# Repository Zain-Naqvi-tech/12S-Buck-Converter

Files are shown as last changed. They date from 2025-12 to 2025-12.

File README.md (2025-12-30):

## Overview
This project is a custom DC-DC Step-Down (Buck) Converter designed in Altium Designer. It takes a higher input voltage and efficiently steps it down to a lower, stable output voltage suitable for powering microcontrollers, sensors, or other low-voltage electronics.

## Specifications
| Parameter | Value |
| :--- | :--- |
| **Input Voltage (Vin)** | 36V - 50.4V |
| **Output Voltage (Vout)** | 5V |
| **Max Output Current** | 3A |
| **Switching Frequency** | 500kHz |
| **Main Controller IC** | LMR16030SDDAR |

Buck Converter PCB 3D Image

Buck Converter PCB 2D Image

Buck Converter Schematic Image

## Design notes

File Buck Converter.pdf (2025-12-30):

### Buck Converter 12S - 5V at 3A

We are required to create a buck converter that steps down voltage from the 12S range (36V to 50.4V) to 5V at 3A.

This is a high voltage input. Therefore, I will be using LMR16030SDDAR as the IC. This IC functions as a high-speed on/off switch which is needed for a buck converter. This is mainly used for the calculation of the Duty Cycle, which is a percentage of time the switch is on.

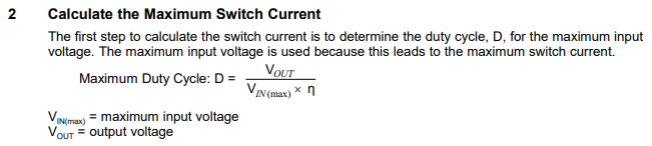
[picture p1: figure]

[1] ‘Basic calculation of a Buck Converter’s Power Stage’ by Texas Instruments.

Efficiency of the converter is estimated to be 90%. [1]
Vout = 5V
Vin = 50.4V (max)

Duty Cycle = 0.11

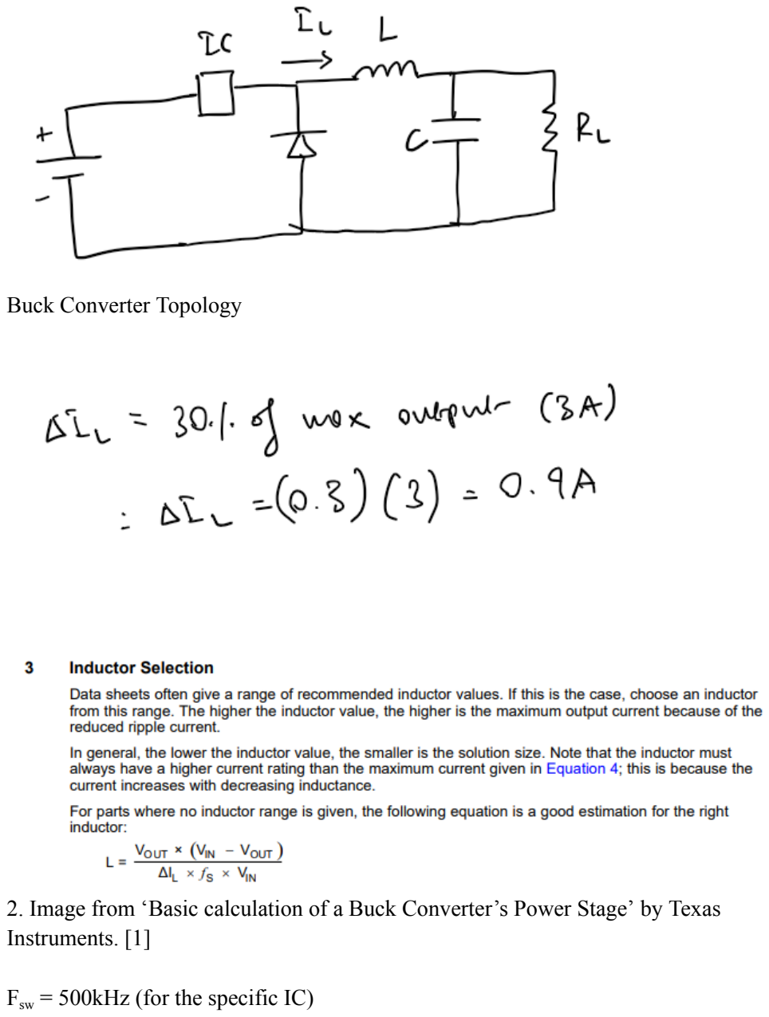
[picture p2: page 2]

Buck Converter Topology

2. Image from ‘Basic calculation of a Buck Converter’s Power Stage’ by Texas Instruments. [1]

Fsw = 500kHz (for the specific IC)

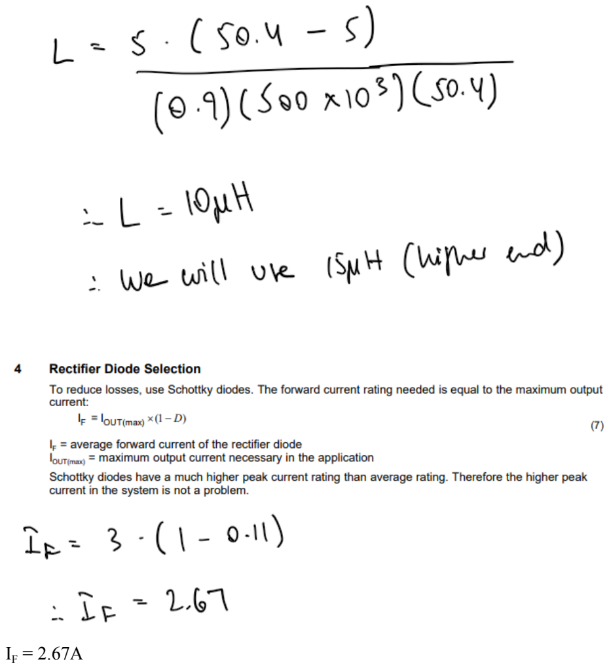
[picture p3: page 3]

IF = 2.67A

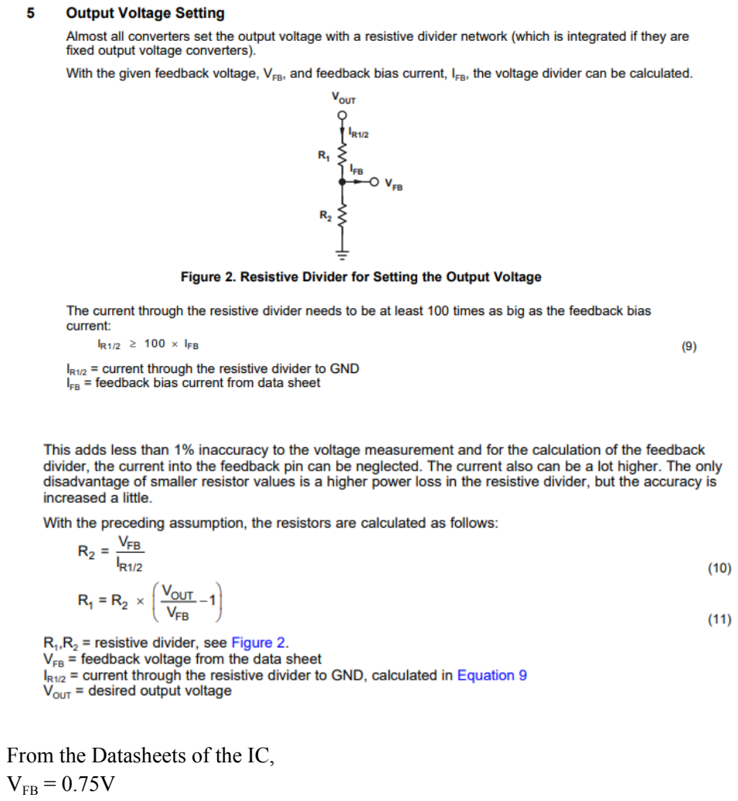
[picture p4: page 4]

From the Datasheets of the IC, VFB = 0.75V

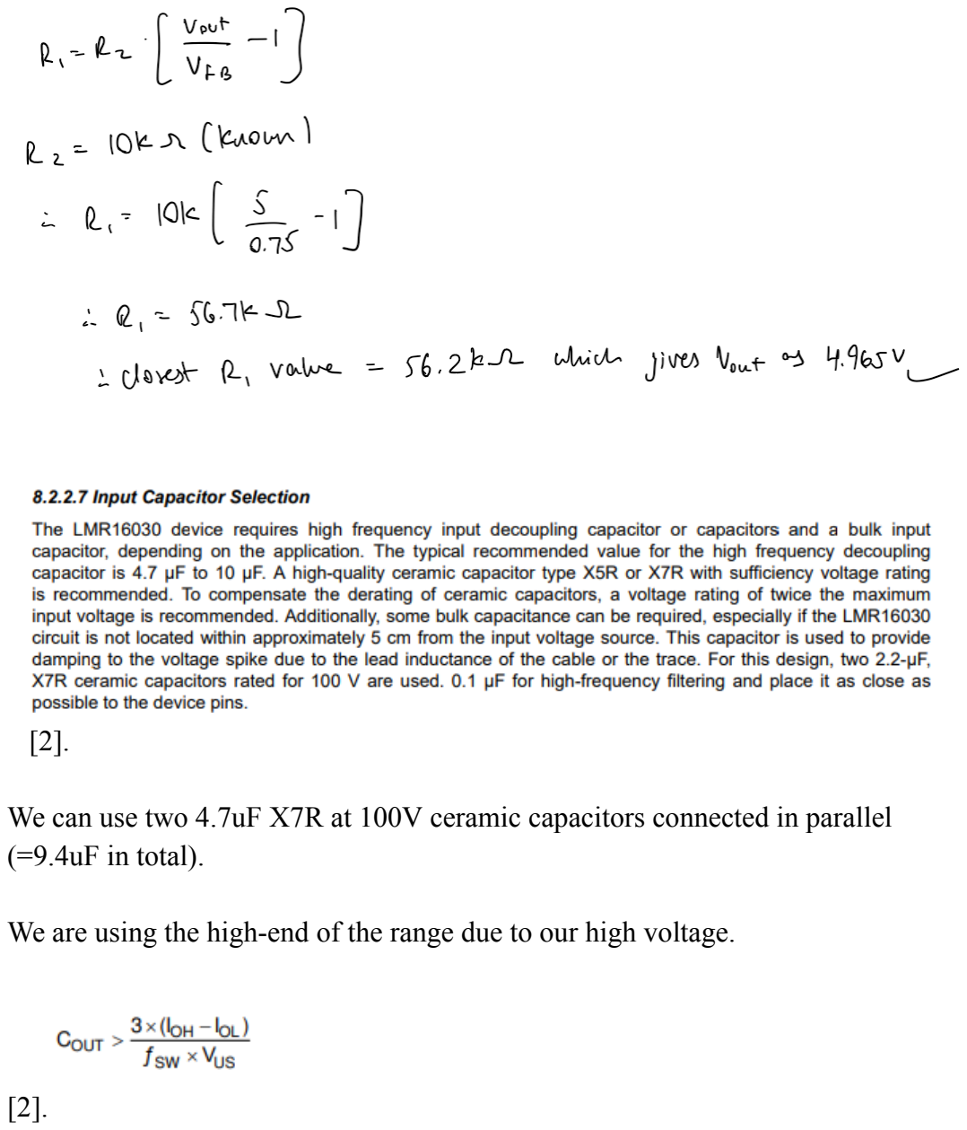
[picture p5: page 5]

[2].

We can use two 4.7uF X7R at 100V ceramic capacitors connected in parallel (=9.4uF in total).

We are using the high-end of the range due to our high voltage.

[2].

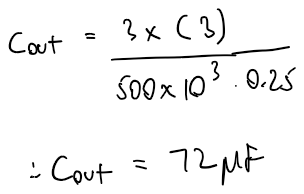
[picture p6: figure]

Cout > 72uF

Therefore, we can use two 47uF at 16V capacitors in parallel (=94uF) which is greater than the min for Cout

RT = 49.9kΩ [2]. - Taken from the datasheet

CBOOT = 0.1uF [2]. - Taken from the datasheet

CSS

:

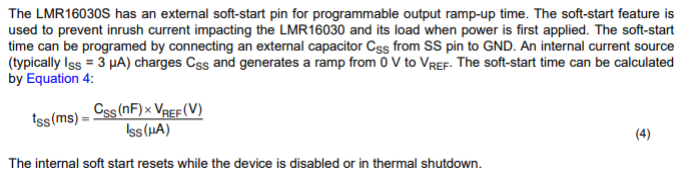
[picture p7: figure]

We can pick a start time of about 4ms. VREF

is 0.75V. ISS

is given as 3uA.

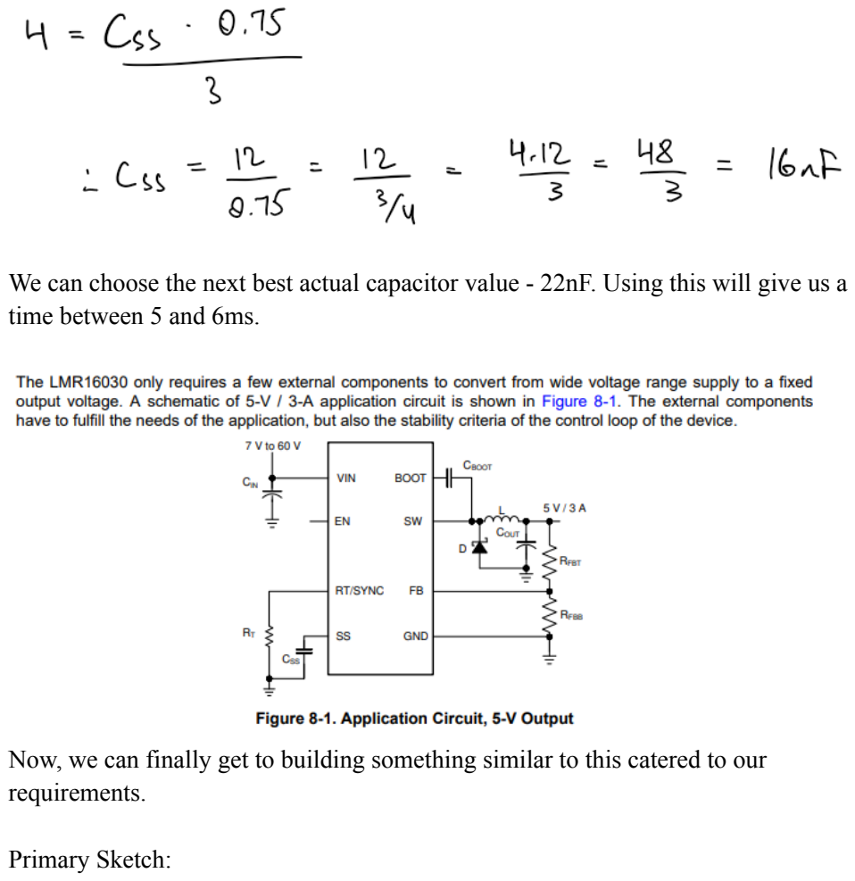
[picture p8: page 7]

We can choose the next best actual capacitor value - 22nF. Using this will give us a time between 5 and 6ms.

Now, we can finally get to building something similar to this catered to our requirements.

Primary Sketch:

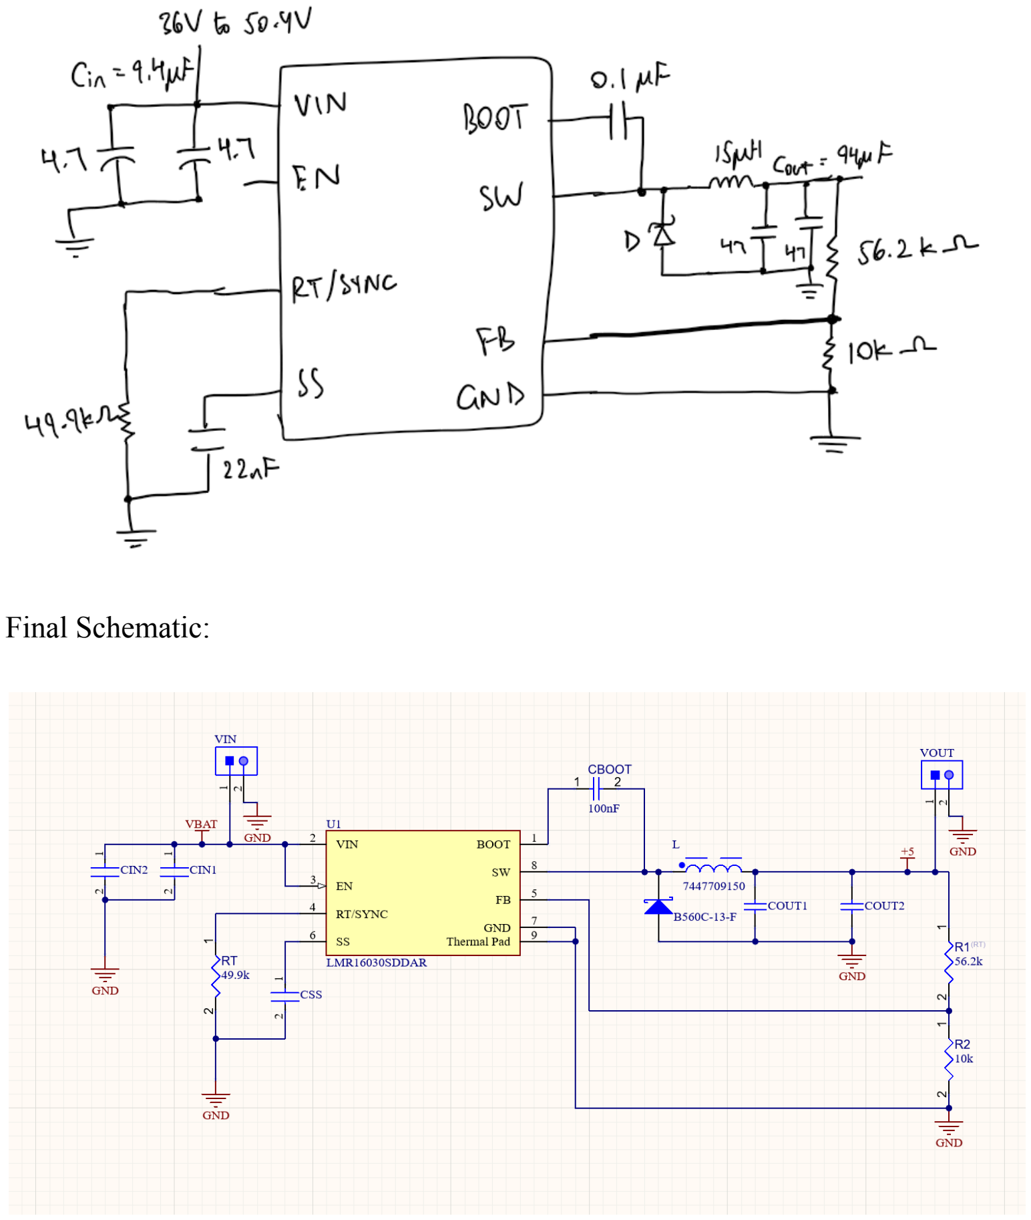
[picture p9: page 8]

Final Schematic:

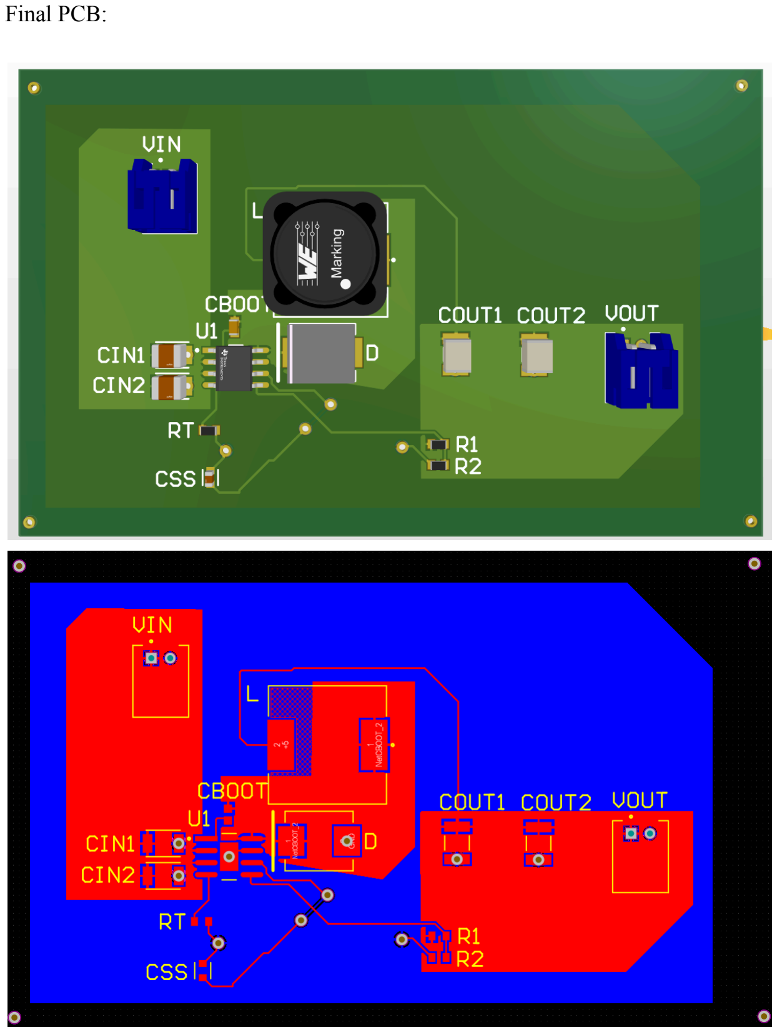
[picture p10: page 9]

Final PCB:

References

[1]. B. Hauke, "Basic Calculation of a Buck Converter's Power Stage," Application Report SLVA477B, Texas Instruments, Dallas, TX, USA, Aug. 2015. [Online]. Available: https://www.ti.com/lit/an/slva477b/slva477b.pdf

[2]. LMR16030 SIMPLE SWITCHER® 60-V, 3-A Step-Down Converter With 40-µA IQ datasheet (Rev. B) SNVSAH9B, Texas Instruments, Dallas, TX, USA, Mar. 2021. [Online]. Available: https://www.ti.com/lit/ds/symlink/lmr16030.pdf

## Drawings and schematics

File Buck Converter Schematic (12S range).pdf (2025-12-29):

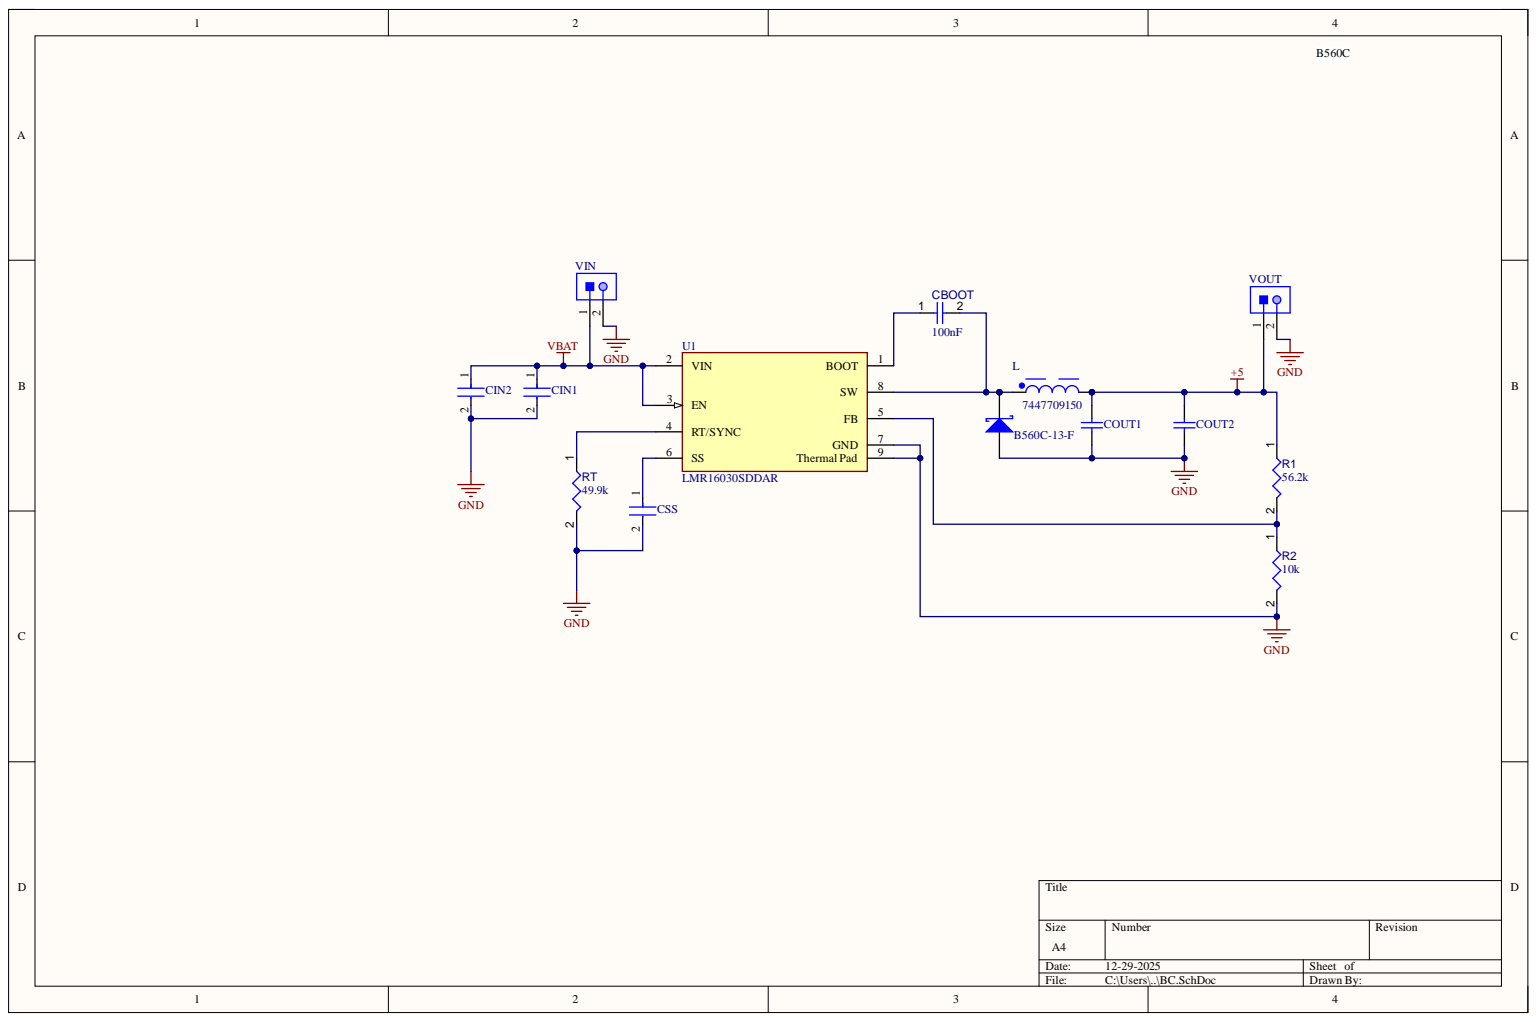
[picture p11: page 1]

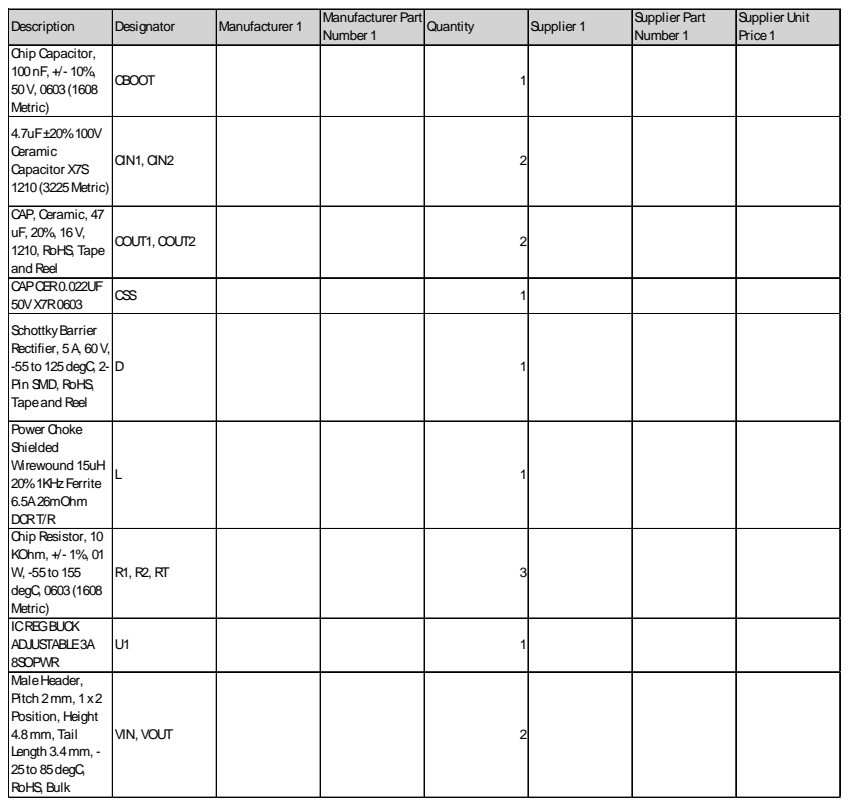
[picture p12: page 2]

Description | Designator | Manufacturer 1 | Manufacturer Part Number 1 | Quantity | Supplier 1 | Supplier Part Number 1 | Supplier Unit Price1

Chip Capacitor, 100nF, +/- 10%, 50V, 0603(1608 Metric) | CBOOT | | | 1

4.7uF±20%100V Ceramic Capacitor X7S 1210(3225Metric) | CIN1, CIN2 | | | 2

CAP, Ceramic, 47 uF, 20%, 16V, 1210, RoHS, Tape and Reel | COUT1, COUT2 | | | 2

CAPCER0.022UF 50VX7R0603 | CSS | | | 1

SchottkyBarrier Rectifier, 5A, 60V, -55to 125degC, 2-Pin SMD, RoHS, Tapeand Reel | D | | | 1

Power Choke Shielded Wirewound 15uH 20%1KHzFerrite 6.5A26mOhm DCRT/R | L | | | 1

Chip Resistor, 10 KOhm, +/- 1%, 01 W, -55to 155 degC, 0603(1608 Metric) | R1, R2, RT | | | 3

ICREGBUCK ADJUSTABLE3A 8SOPWR | U1 | | | 1

MaleHeader, Pitch 2mm, 1x2 Position, Height 4.8mm, Tail Length 3.4mm, -25to 85degC, RoHS, Bulk | VIN, VOUT | | | 2

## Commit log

2025-12-29 Added the Schematic File
    The file consists of the schematic and a table of every component used along with their quantities.
2025-12-29 Fix punctuation in input voltage description
2025-12-29 Added the Altium Schematic File
    [BC.SchDoc]
2025-12-29 Enhance README with project details and specs
    Added project overview and specifications for the Buck Converter.
2025-12-29 Update specifications for buck converter
2025-12-30 Add image to README for Buck Converter project
    Added an image to the README for visual reference.
2025-12-30 Fix image link in README.md
    Updated image source for the Buck Converter project.
2025-12-30 Add images to README for Buck Converter
    Added images of the Buck Converter PCB and schematic.
2025-12-30 Remove brackets from specifications values
